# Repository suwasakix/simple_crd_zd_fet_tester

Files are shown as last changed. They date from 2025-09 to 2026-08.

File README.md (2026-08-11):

# Simple CRD/ZD/FET Tester

定電流ダイオード/定電圧ダイオード/FET 簡易測定器

&nbsp;

## 目次 - Contents

 - [このプリント基板について](#このプリント基板について---about-this-pcb)
 - [ガーバーデータのダウンロード](#ガーバーデータのダウンロード---download-gerber-data)
 - [回路図](#回路図---pcb-schematic)
 - [レイアウト](#レイアウト---pcb-layout)
 - [部品リスト](#部品リスト---parts-list)
 - [便利なアイテム](#便利なアイテム---useful-items)
 - [使用例](#使用例---example-of-use)
 - [開発環境](#開発環境---development-environment)
 - [ライセンスについて](#ライセンスについて---license)

&nbsp;

## このプリント基板について - About this PCB

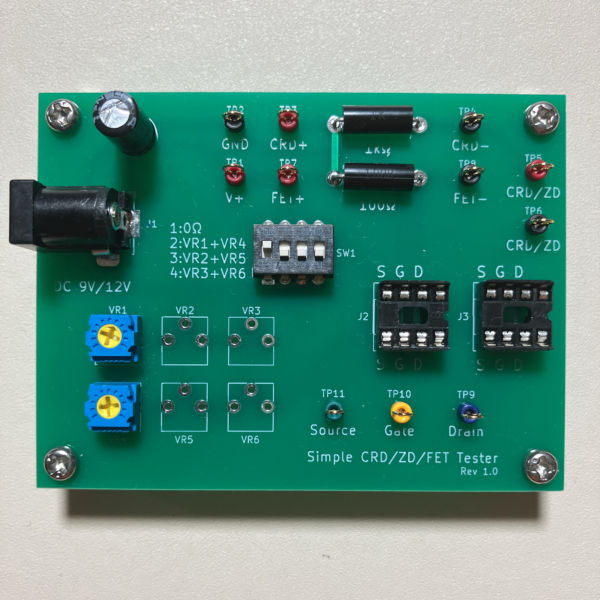
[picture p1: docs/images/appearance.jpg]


このプリント基板は、ぺるけさんの [6AH4GT 全段差動プッシュプル・アンプ](http://www.op316.com/tubes/myamp/6ah4pp.htm) のページで紹介されている定電流ダイオード(CRD)・定電圧ダイオード(ZD)・FETの簡易測定回路を１枚の基板にまとめたものです。  

この基板では、CRD の電流値、ZD のツェナー電圧、J-FET の Idss およびバイアスの測定ができます。  

この基板は CRD、ZD、FET の簡易測定を目的としたものであり、自作のアンプに使用する半導体部品を選別するのに向いています。選別した半導体部品を第三者に頒布することを目的とする場合は、電流と電圧の両方を調整できるような高機能な測定器が必要になると思います。  

&nbsp;

## ガーバーデータのダウンロード - Download gerber data

こちらのページから「simple_crd_zd_fet_tester-gerber.zip」のファイルをダウンロードしてください。  

&emsp; https://www.github.com/suwasakix/simple_crd_zd_fet_tester/releases

このプロジェクトは、各自がプリント基板のガーバーデータをダウンロードして PCB 基板メーカーに基板製造を発注することを前提にしています。個人で発注可能な PCB 基板メーカーは国内外問わずありますが、近年では 10cm 四方以下の基板サイズであれば海外メーカーで格安に製造委託することが可能になりました。発注例として、深圳の Seeed studio が提供する PCB 製造サービス「[Fusion PCB](https://www.fusionpcb.jp)」に基板製造を発注する方法を[こちらのページ](docs/ORDER_PCB.md)で紹介しておきます。

本リポジトリの Release で公開しているガーバーデータは、Fusion PCB に発注して問題なく基板が製造されることを確認しております。

&nbsp;

## 回路図 - PCB schematic

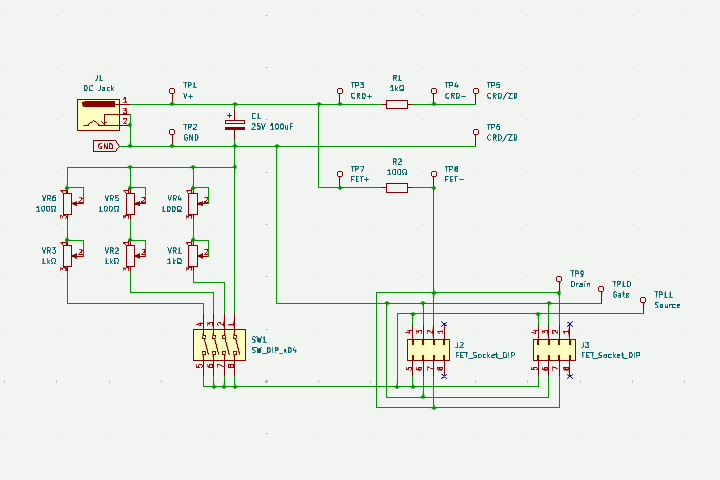
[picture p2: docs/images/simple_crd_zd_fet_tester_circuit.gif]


CRD/ZD/FET の選別をしたことがある方には特に説明の必要もない回路ですが、使い方が分からない方は[使用例](#使用例---example-of-use)に目を通していただければと思います。

R1, R2 は電流値を測定するための抵抗なので高精度品か、あるいは抵抗値を実測してなるべく 1kΩ / 100Ω に近いものを使用してください。

VR1 ～ VR6 は FET のバイアス調整用の半固定ボリュームです。半固定ボリュームは実機回路のバランスを調整するために使われる部品で一旦調整が完了したら動かさないことから、一般的に半固定ボリュームの回転寿命は長くありません（ボリュームの回転を繰り返しているうちに接触面が劣化して抵抗値の調整ができなくなります）。本来であれば回転寿命がより長いボリュームを割り当てるべきですが、本基板は自作アンプの部品選別することが目的なので、使用頻度が多くなることはないだろうと判断して割り切りました。最初は VR1 と VR2 を使って、それらがダメになったら VR3 と VR4 を使って、その次に VR5 と VR6 で……と、半固定ボリュームは消耗品扱いの前提で使用しています。

電源には 9V または 12V の AC アダプターを使用してください。DC ジャックは 外径 5.5mm / 内径 2.1mm センタープラスのものが適合します。9V 角型電池に DC プラグ付 9V 電池スナップを接続して使ってもかまいません。

&nbsp;

## レイアウト - PCB layout

* 基板サイズ : W 80mm × H 60mm

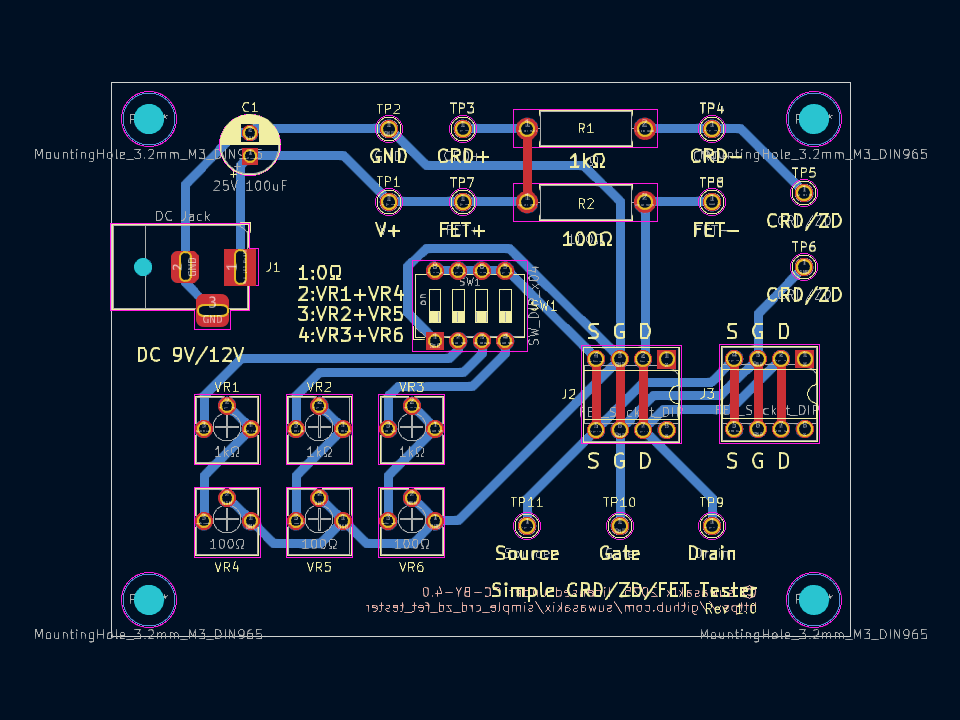
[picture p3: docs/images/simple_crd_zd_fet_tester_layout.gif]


&nbsp;

## 部品リスト - Parts list

* 通販による部品販売では、10個単位などでまとめ売りされている場合がしばしばあります。注文の際にはご注意ください。
* ☆ は使用しなければ省略可。

|部品種別			|記号					|部品名															|値				|個数		|入手ルート																												|
|:----:				|:----:					|:----:															|:----:			|:----:		|:----:																													|
|抵抗				|R1						|金属皮膜抵抗 1/4W												|1kΩ			|1			|[高精度 金属皮膜抵抗 1/2W1kΩ ±0.1%][AK_108510_R1k]<br>[高精度 金属皮膜抵抗 1/4W1kΩ ±0.1%][AK_108505_R1k]			|
|					|R2						|金属皮膜抵抗 1/4W												|100Ω			|1			|[高精度 金属皮膜抵抗 1/2W100Ω ±0.1%][AK_108509_R100]<br>[高精度 金属皮膜抵抗 1/4W100Ω ±0.1%][AK_108504_R100]		|
|半固定抵抗			|VR1 ～ VR3 ☆			|半固定抵抗<br>(FETバイアス粗調整用)							|1kΩ			|1 ～ 3		|[半固定ボリューム GF063P 1kΩ][AK_114901_VR1k]																			|
|					|VR4 ～ VR6 ☆			|半固定抵抗<br>(FETバイアス微調整用)							|100Ω			|1 ～ 3		|[半固定ボリューム GF063P 100Ω][AK_114897_VR100]																		|
|コンデンサ			|C1						|電解コンデンサ<br>(直径 6.3mm,<br>リードピッチ 2.5mm)			|100μF			|1			|[100μF35V105℃ ルビコンZLH][AK_102724_C35v100u]																		|
|スイッチ			|SW1					|4極 DIPスイッチ												|-				|1			|[DIPスイッチ 4P KSD42][AK_108923_SW_KSD42]																				|
|チェック端子		|TP1 ～ TP11 ☆			|チェック端子													|-				|8			|[チェック端子][AK_C_CCHECKTER]																							|
|ソケット			|J1						|基板型DCジャック<br>(内径2.1mm, 外径5.5mm)						|-				|1			|[MJ-179P][AK_100077_MJ-179P]<br>[2DC0005D100 1パック4個入][AK_101604_2DC0005D100]										|
|					|J2, J3 ☆				|8ピン 板バネICソケット											|-				|2			|[2227-08-03 1パック10個入][AK_100017_2227-08-03]																		|
|基板スペーサー		|						|黄銅六角スペーサー<br>M3×10mm									|-				|4			|[FB3-10][AK_107313_FB3-10]																								|
|					|						|M3 ネジ								 						|-				|4			|(ホームセンター等で入手可能)																							|

[AK_108510_R1k]:								https://akizukidenshi.com/catalog/g/g108510/
[AK_108505_R1k]:								https://akizukidenshi.com/catalog/g/g108505/
[AK_108509_R100]:								https://akizukidenshi.com/catalog/g/g108509/
[AK_108504_R100]:								https://akizukidenshi.com/catalog/g/g108504/
[AK_114901_VR1k]:								https://akizukidenshi.com/catalog/g/g114901/
[AK_114897_VR100]:								https://akizukidenshi.com/catalog/g/g114897/
[AK_102724_C35v100u]:							https://akizukidenshi.com/catalog/g/g102724/
[AK_108923_SW_KSD42]:							https://akizukidenshi.com/catalog/g/g108923/
[AK_C_CCHECKTER]:								https://akizukidenshi.com/catalog/c/ccheckter/
[AK_100077_MJ-179P]:							https://akizukidenshi.com/catalog/g/g100077/
[AK_101604_2DC0005D100]:						https://akizukidenshi.com/catalog/g/g101604/
[AK_100017_2227-08-03]:							https://akizukidenshi.com/catalog/g/g100017/
[AK_107313_FB3-10]:								https://akizukidenshi.com/catalog/g/g107313/

R1, R2 は金属皮膜抵抗の高精度品を使用するか、あるいは誤差±1%の金属皮膜抵抗から選別したものを割り当てます。普及価格帯のデジタルマルチメーターの場合、抵抗値の確度（測定誤差）はおおよそ ±0.5% ～ ±1.0% といったところなので、高精度品を使用した方が外れは少ないことになります。ただし、高精度品を使用する場合でも部品の不良チェックのために抵抗値は実測しておくようにしてください。

FET のバイアス測定を行わない場合、VR1 ～ VR6 は不要です。少なくとも VR1, VR2 のみを実装すればバイアス測定は可能です。

J2, J3 は FET 用のソケットです。使わないソケットは省略することもできます。TP9 ～ TP11 から線出しして IC クリップで測定する FET を繋いでもよいです。

ショート事故防止のため、必ず基板スペーサーを付けて使用してください。

&nbsp;

## 便利なアイテム - Useful items

|部品名																			|入手ルート																																				|
|:----:																			|:----:																																					|
|ACアダプター 12V<br>(DCプラグ内径2.1mm, 外径5.5mm,<br>センタープラス)			|[M120100-A010JP][AK_117429_ACDC12V_M120100-A010JP]<br>[AD-M120P100][AK_111994_ACDC12V_AD-M120P100]<br>[AD-K120P100][AK_106642_ACDC12V_AD-K120P100]		|
|DCプラグ付9V電池スナップ<br>(DCプラグ内径2.1mm, 外径5.5mm,<br>センタープラス)	|[BS-IR-1][AK_107356_DCP_BS-IR-1]																														|
|テストリード<br>(バナナプラグ ⇔ ICクリップ)									|[TLA-106][AK_112359_TLA-106]																															|
|テストリード<br>(ICクリップ両端)												|[TLA-105][AK_112419_TLA-105]<br>[TLA-101][AK_111765_TLA-101]																							|

[AK_117429_ACDC12V_M120100-A010JP]:				https://akizukidenshi.com/catalog/g/g117429/
[AK_111994_ACDC12V_AD-M120P100]:				https://akizukidenshi.com/catalog/g/g111994/
[AK_106642_ACDC12V_AD-K120P100]:				https://akizukidenshi.com/catalog/g/g106642/
[AK_107356_DCP_BS-IR-1]:						https://akizukidenshi.com/catalog/g/g107356/
[AK_112359_TLA-106]:							https://akizukidenshi.com/catalog/g/g112359/
[AK_112419_TLA-105]:							https://akizukidenshi.com/catalog/g/g112419/
[AK_111765_TLA-101]:							https://akizukidenshi.com/catalog/g/g111765/

&nbsp;

## 使用例 - Example of use

### 定電流ダイオード (CRD) の測定

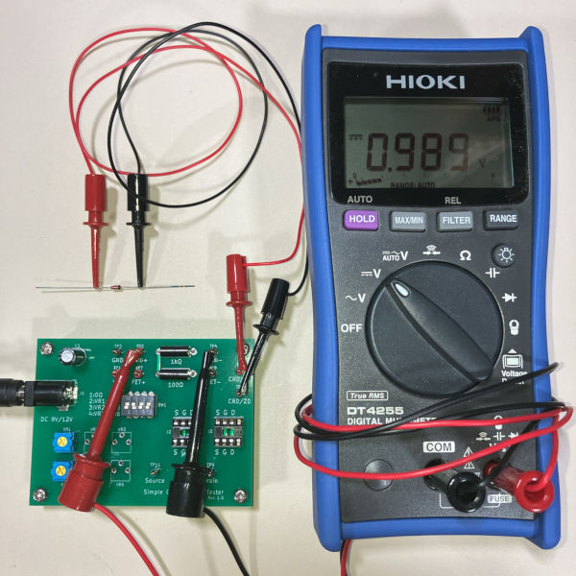
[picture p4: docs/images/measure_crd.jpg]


テスターを CRD+ と CRD- の端子に、定電流ダイオードを CRD/ZD の両端子に接続します。

テスターに表示された電圧値 (V) が定電流ダイオードの電流値 (mA) になります。

&nbsp;

### 定電圧ダイオード (ZD) の測定

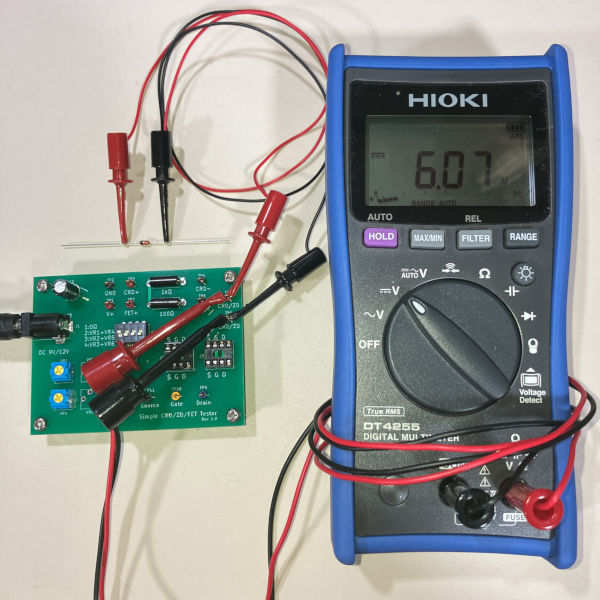
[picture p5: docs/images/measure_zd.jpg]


テスターと定電流ダイオードの両方を CRD/ZD の両端子に接続します。

テスターに表示された電圧値 (V) が定電圧ダイオードのツェナー電圧 (V) になります。

&nbsp;

### FET のドレイン飽和電流 (Idss) の測定

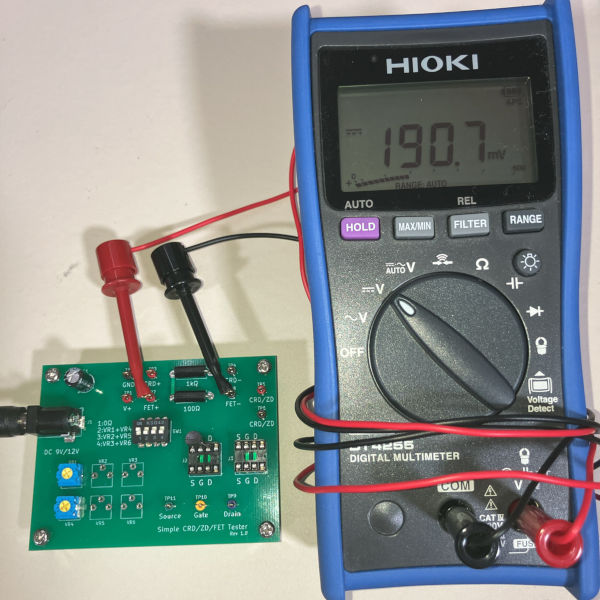
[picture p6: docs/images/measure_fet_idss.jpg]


DIP スイッチの SW1 のみを ON にした状態で、テスターを FET+ と FET- の端子に接続し、FET をソケットに差し込みます。

テスターに表示された電圧値 (mV) を 100で割った（小数点を左に２桁スライドさせた）値が FET のドレイン飽和電流 (mA) になります。

&nbsp;

### FET のドレイン電流 - バイアスの測定

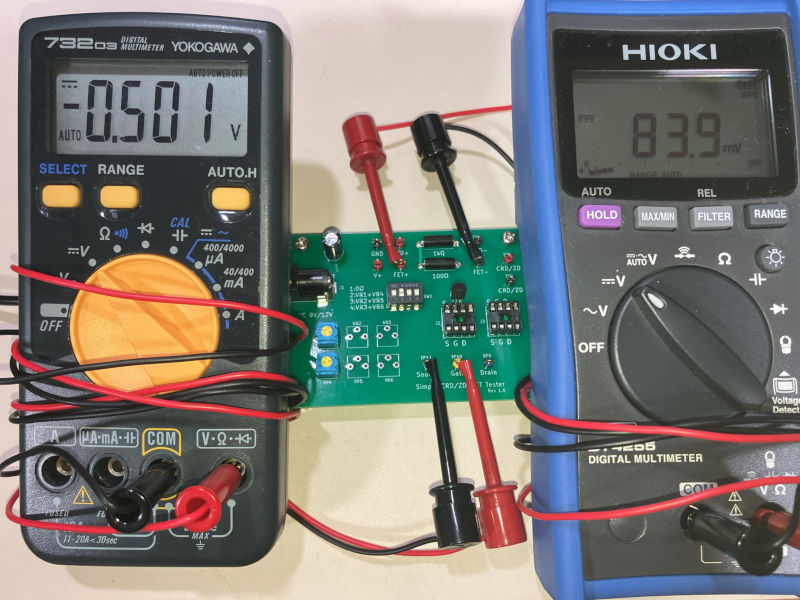
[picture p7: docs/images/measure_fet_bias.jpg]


ドレイン飽和電流と同様ですが、DIP スイッチは SW2 ～ SW4 のいずれかに合わせてください。

SW に対応した半固定抵抗を操作してバイアスを調整すると、バイアス電圧とドレイン電流の関係を調べることができます。

この方法は FET を使って定電流回路を作るときに必要な抵抗値を調べるのに役立ちます（抵抗値を測定する際には必ず基板の電源を抜いてください）。

&nbsp;

## 開発環境 - Development environment

このプリント基板の設計データは、[KiCad](https://www.kicad.org) 9.0 で作成しています。基板のデータは KiCad 9.0 以降で編集することができます。  

なお、この基板のデータを改変するには KiCad ライブラリ [Victwale](https://github.com/suwasakix/Victwale) を必要とします。  

&nbsp;

## ライセンスについて - License

このプリント基板の設計データのライセンスは [Creative Commons CC-BY 4.0 License](https://creativecommons.org/licenses/by/4.0/legalcode) です。

- 上記設計データの著作権は作者 (suwasakix) が保持します。ただし、著作権が生じるのは設計データのレイアウトのみであり、回路図に著作権は生じません。

- 上記設計データは、何の制限もなく私的に利用することができます。データを自由に改変して私的に利用することもできます。

- 上記設計データに変更を加えることなく製造したプリント基板は、商用・非商用を問わず何の制限もなく第三者に頒布することができます。

- 上記設計データの改変物、または改変物をもとに製造したプリント基板（二次創作物）を第三者に頒布するには、原作品が著作権者 (suwasakix) のものであること、および当該作品が二次創作物であることを明示する必要があります。一例としては、原作品の著作権者、および二次創作物の著作権者を当該作品に明示すれば問題ありません。

  - なお、それらを明示する手段は当該作品の実物以外に、当該作品の設計データの一時配布元でもよいものとします（当該作品に著作権者の情報を記載する物理的なスペースがない場合には、一時配布元に著作権者の情報を記載することで代えることが可能です）。その場合、当該作品の実物にデータの一時配布元が記載されていなければなりません。

- 上記設計データの二次創作物には、原作品とは異なるライセンスを適用することができます。

- 上記ライセンスは著作権者からの一方的な利用許諾条件です。利用するにあたり著作権者への連絡は一切不要です。

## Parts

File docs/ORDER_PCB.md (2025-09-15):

# PCB 基板の発注方法 - How to order PCB

このページでは PCB 基板を発注する方法について説明します。

&nbsp;

## Fusion PCB に基板を発注

[Fusion PCB](https://www.fusionpcb.jp) への基板の発注は、[基板製造見積ページ](https://www.fusionpcb.jp/fusion_pcb.html)から行います。  

&nbsp;

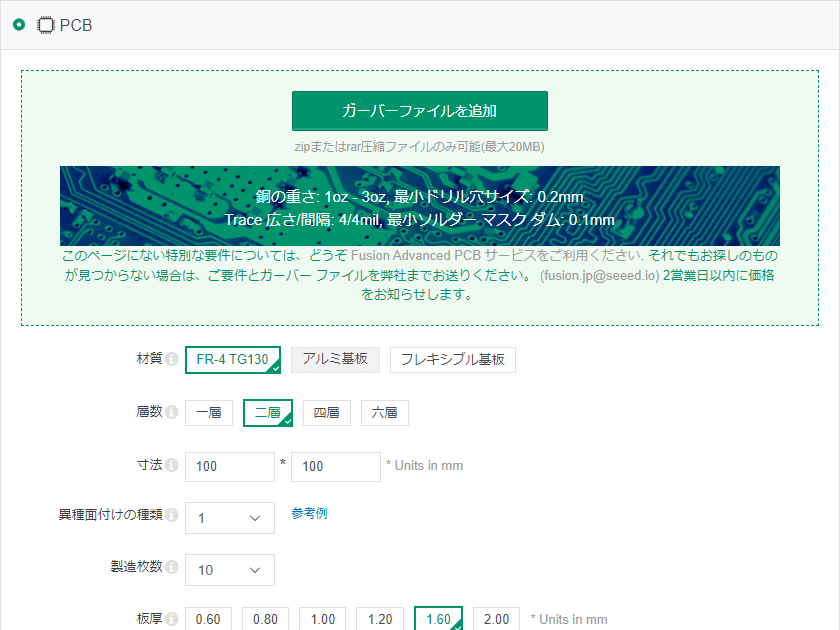
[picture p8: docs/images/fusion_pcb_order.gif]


まず、画面にある「ガーバーファイルを追加」をクリックして、Releases のページからダウンロードしたガーバーファイル（ファイル名が「-gerber.zip」で終わるファイル）を選択してください。  

ガーバーファイルを追加後に「ドリル ファイルが見つかりません。 Excellon 形式の NC ドリル ファイルが含まれていることを確認してください。」というメッセージが出ますが、無視して差し支えありません。リポジトリに登録したガーバーファイルにはドリルファイルが含まれており、Fusion PCB で基板が正常に製造されることを確認しております。

&nbsp;

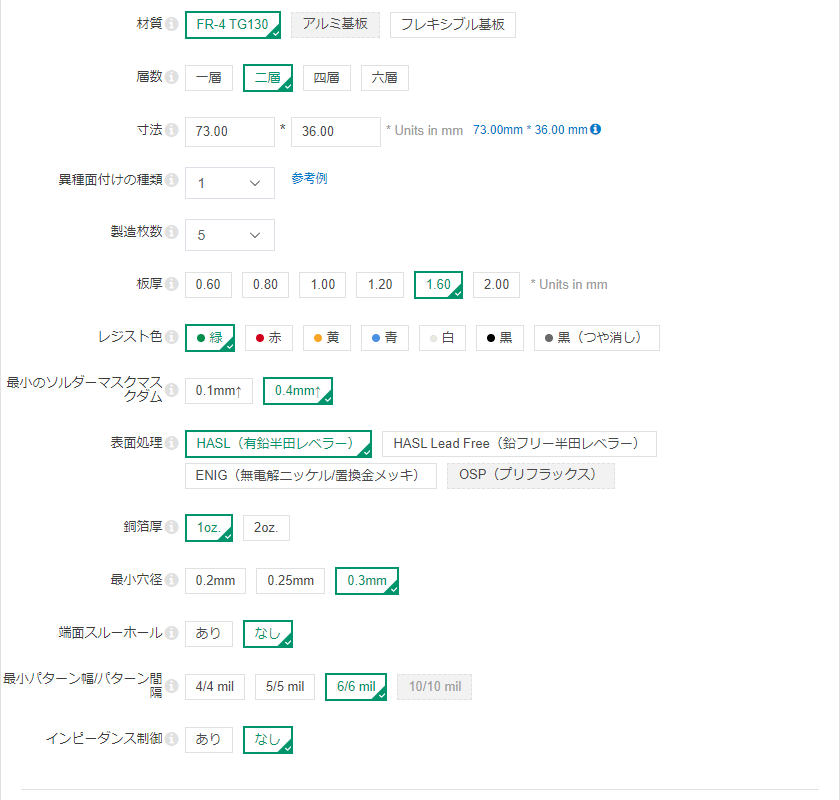
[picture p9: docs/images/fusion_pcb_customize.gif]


設定パラメータは色々ありますが、一例を以下に示します。  

- 材質 : FR-4 TG130
- 層数 : 二層
- 寸法 : (ガーバーデータから自動的に設定されます)
- 製造枚数 : 最小5枚 (デフォルト:10枚)
- 異種面付けの種類 : 1
- 板厚 : 1.60
- レジスト色 : 緑/赤/黄/青/白/黒 から選択可能 (デフォルト:緑)
- 表面処理 : HASL/HASL Lead Free/ENIG/OSP から選択可能 (デフォルト:HASL)
- 最小のソルダーマスクマスクダム : 0.4mm↑
- 銅箔厚 : 1oz.
- 最小穴径 : 0.3mm
- 端面スルーホール : なし
- 最小パターン幅/パターン間隔 : 6/6 mil
- インピーダンス制御 : なし

基板の寸法が 100mm x 100mm を超えたとたんに金額が１桁跳ね上がるため、基板の大きさは極力これ以下のサイズで設計したいところです。  

製造枚数は最小で5枚を指定することができますが、金額は5枚と10枚とで変わりはありません。  

基板の色はレジスト色で指定することができます。緑色以外も選ぶことができるので、そこは各人の好みで。  

基板の表面処理は HASL (有鉛半田レベラー) が最も低コストですが、RoHS 指令に従わなければいけない人や意識高めの人は鉛フリーの HASL Lead Free にしましょう。金フラッシュでなければ嫌だという人なら ENIG 一択になりますが、お値段もお高くなりますのでそのつもりで。  

板厚など他の設定は、デフォルトのままで問題ないと思います。

設定が終わったら画面右側の「カートに入れる」を選択して、他の基板のオーダーを続けるか、発注手続きを行ってください。  

日本国内であれば、発注から２週間もすれば注文した基板が届くと思います。  

&nbsp;

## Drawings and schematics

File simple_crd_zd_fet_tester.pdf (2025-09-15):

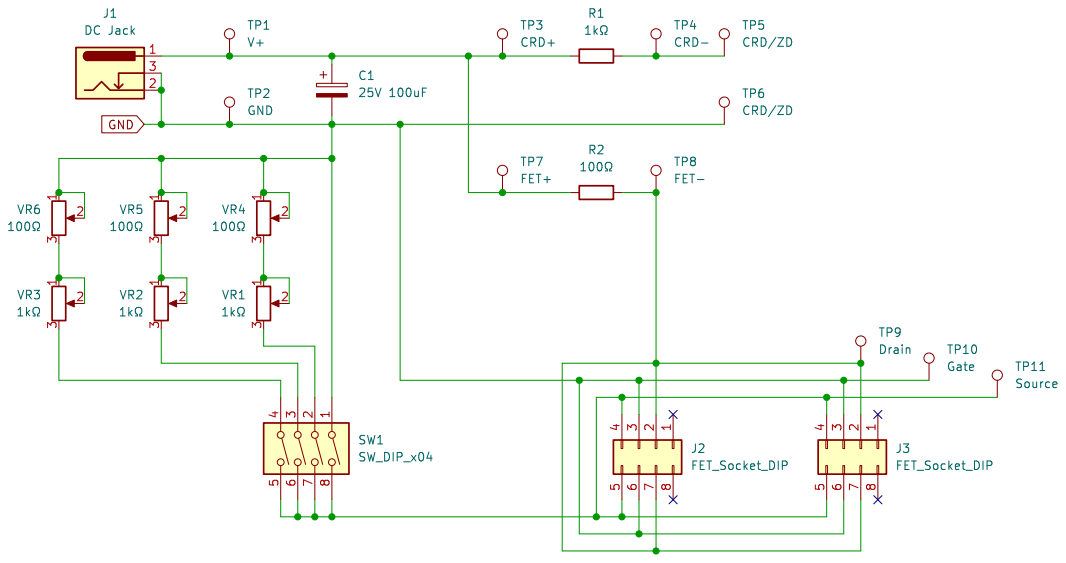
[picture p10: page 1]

https://github.com/suwasakix/simple_crd_zd_fet_tester

Id: 1/1 Title: File: simple_crd_zd_fet_tester.kicad_sch Sheet: /

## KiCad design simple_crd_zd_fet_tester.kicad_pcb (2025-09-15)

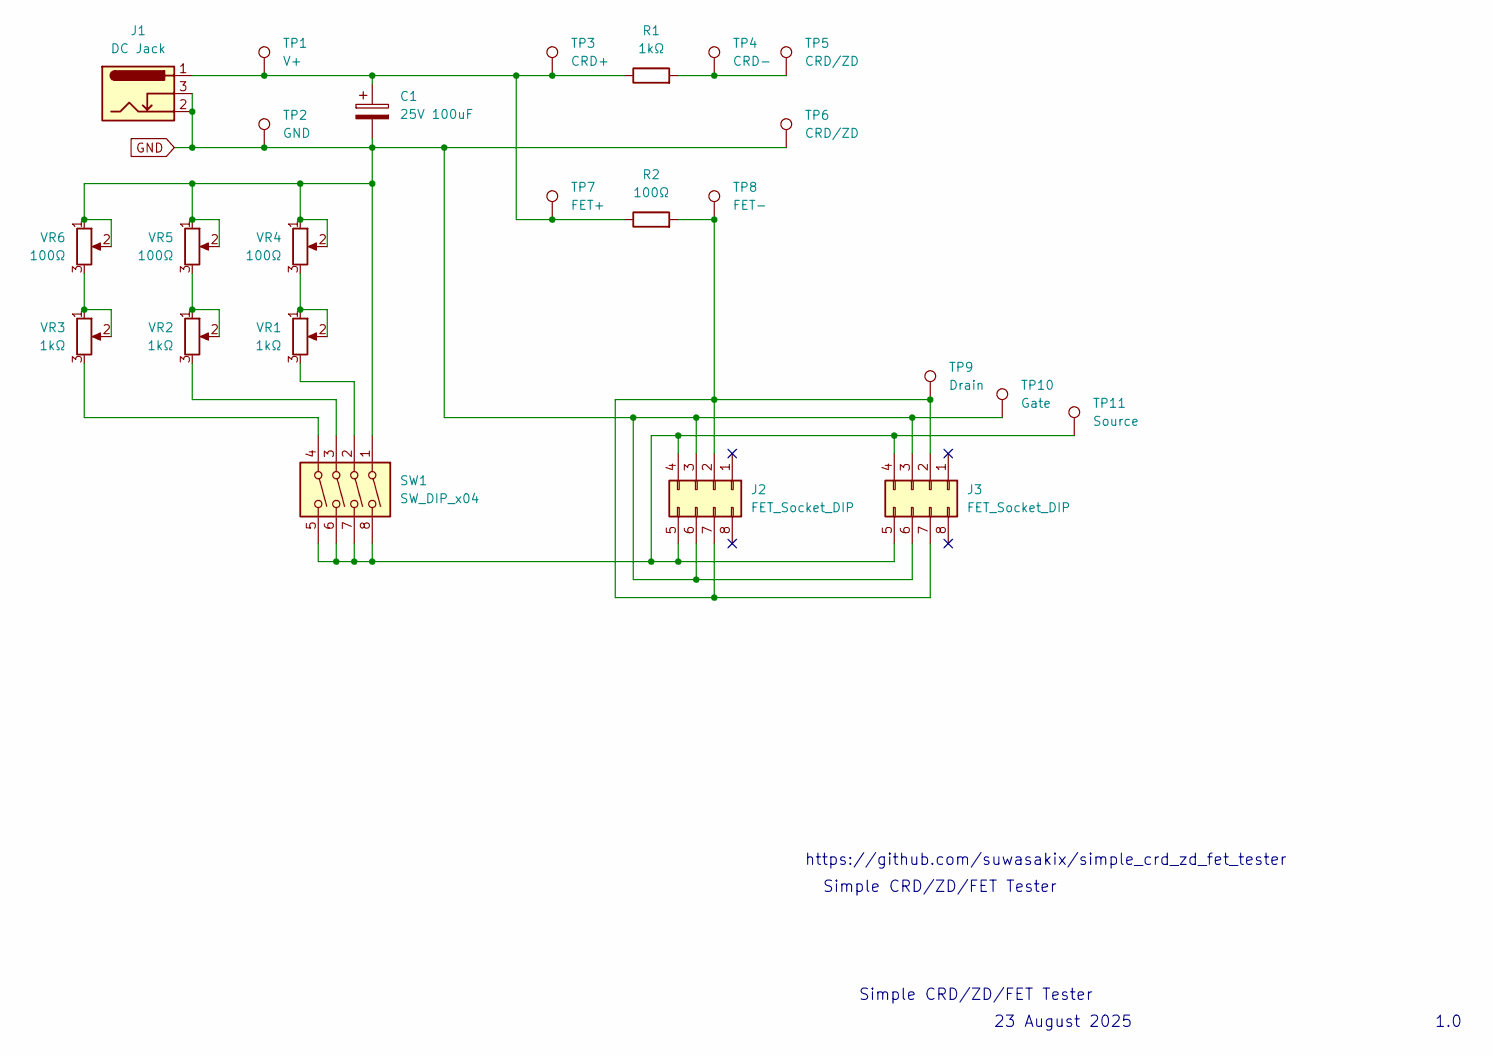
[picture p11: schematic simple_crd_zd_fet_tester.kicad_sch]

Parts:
C1: 25V 100uF; CP_Radial_D6.3mm_P2.50mm
J1: DC Jack; BarrelJack_Horizontal
J2, J3: FET_Socket_DIP; DIP-8_W7.62mm_Socket
R1: 1kΩ; R_Axial_DIN0411_L9.9mm_D3.6mm_P12.70mm_Horizontal
R2: 100Ω; R_Axial_DIN0411_L9.9mm_D3.6mm_P12.70mm_Horizontal
SW1: SW_DIP_x04; SW_DIP_SPSTx04_Slide_6.7x11.72mm_W7.62mm_P2.54mm_LowProfile
TP1: V+; Pin_D1.0mm_L10.0mm
TP2: GND; Pin_D1.0mm_L10.0mm
TP3: CRD+; Pin_D1.0mm_L10.0mm
TP4: CRD-; Pin_D1.0mm_L10.0mm
TP5, TP6: CRD/ZD; Pin_D1.0mm_L10.0mm
TP7: FET+; Pin_D1.0mm_L10.0mm
TP8: FET-; Pin_D1.0mm_L10.0mm
TP9: Drain; Pin_D1.0mm_L10.0mm
TP10: Gate; Pin_D1.0mm_L10.0mm
TP11: Source; Pin_D1.0mm_L10.0mm
VR1, VR2, VR3: 1kΩ; Potentiometer_Vishay_T73YP_Vertical
VR4, VR5, VR6: 100Ω; Potentiometer_Vishay_T73YP_Vertical

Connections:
GND: C1.2, J1.2, J1.3, J2.3, J2.6, J3.3, J3.6, SW1.1, TP2.1, TP6.1, TP10.1, VR4.1, VR4.2, VR5.1, VR5.2, VR6.1, VR6.2
unnamed: C1.1, J1.1, R1.1, R2.1, TP1.1, TP3.1, TP7.1
unnamed: J2.2, J2.7, J3.2, J3.7, R2.2, TP8.1, TP9.1
unnamed: J2.4, J2.5, J3.4, J3.5, SW1.5, SW1.6, SW1.7, SW1.8, TP11.1
unnamed: R1.2, TP4.1, TP5.1
unnamed: SW1.2, VR1.3
unnamed: SW1.3, VR2.3
unnamed: SW1.4, VR3.3
unnamed: VR1.1, VR1.2, VR4.3
unnamed: VR2.1, VR2.2, VR5.3
unnamed: VR3.1, VR3.2, VR6.3

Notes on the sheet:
Simple CRD/ZD/FET Tester
23 August 2025
https://github.com/suwasakix/simple_crd_zd_fet_tester
1.0

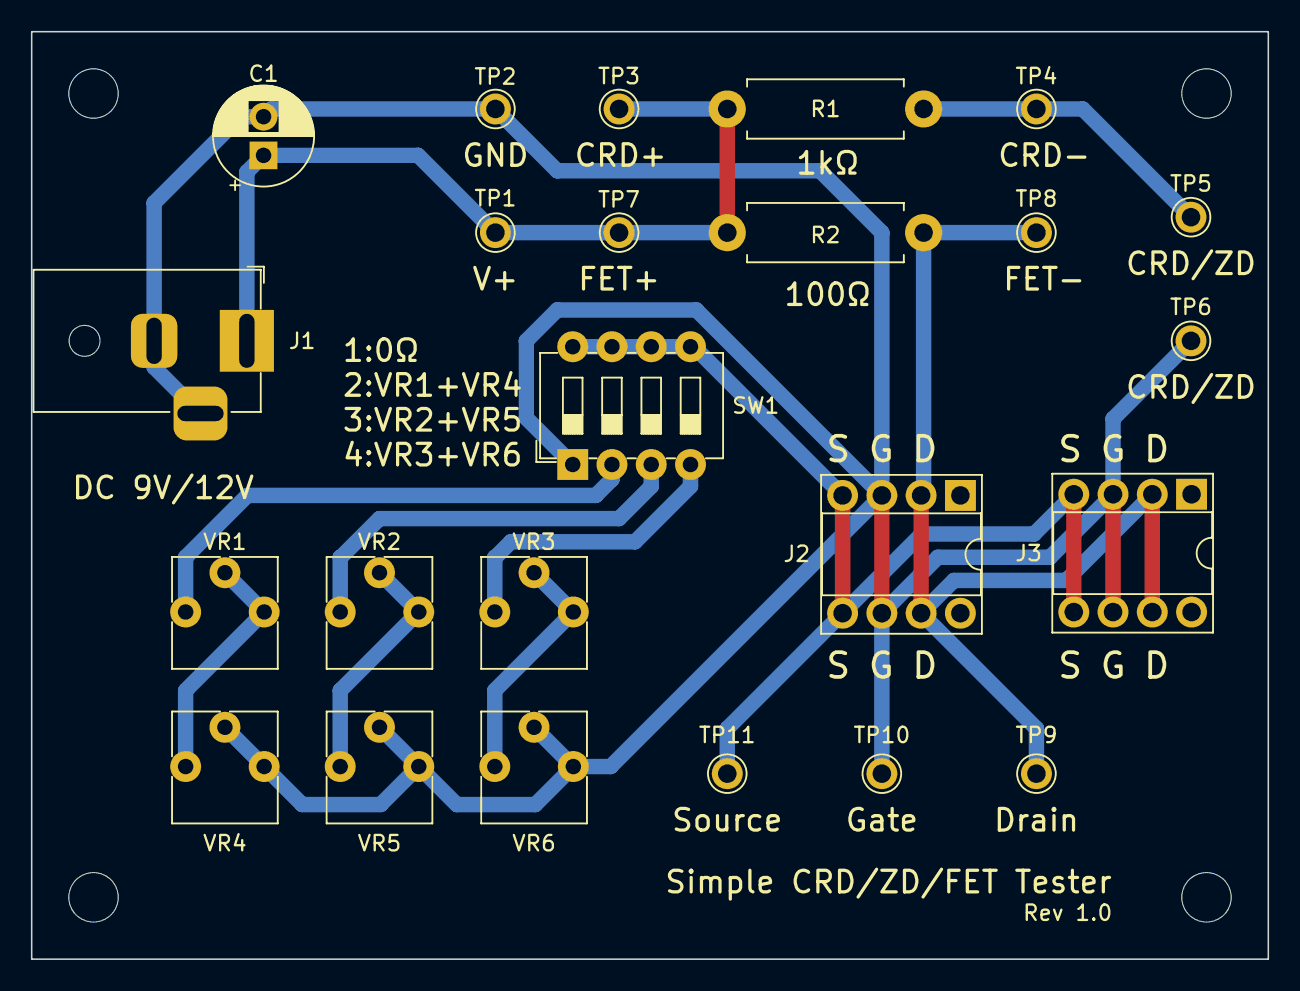
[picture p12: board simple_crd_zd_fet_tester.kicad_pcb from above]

Board: 2 copper layers, 80.0 x 60.0 mm, 24 parts (0 on the bottom side), 11 nets.

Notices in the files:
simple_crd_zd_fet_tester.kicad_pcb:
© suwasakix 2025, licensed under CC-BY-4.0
